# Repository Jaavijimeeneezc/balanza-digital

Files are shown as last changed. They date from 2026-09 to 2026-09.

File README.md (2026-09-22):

# Balanza digital

Lectura automática de básculas analógicas mediante visión por computador. Una
placa ESP32-CAM apunta al display de la báscula y transmite la imagen; el
reconocimiento del peso se hace en el servidor.

## Arquitectura

La placa no calcula el peso. Solo aporta imagen:

1. Se conecta al WiFi y al broker MQTT.
2. Se anuncia en `bascula/{id}/estado` con un mensaje retenido. Ese anuncio
   es todo el descubrimiento: el backend la da de alta sin configurar
   ninguna IP a mano.
3. Sirve video en el puerto 81 y captura puntual en el 80.
4. Escucha órdenes en `bascula/{id}/comando`.

El OCR vive en el backend, que tiene CPU de sobra y se puede afinar sin
reflashear las placas desplegadas.

## Contenido

- `firmware/balanzaDigital_esp32cam/` — firmware principal (MQTT, cámara,
  servidor HTTP).
- `firmware/bascula/` — versión anterior, más simple, que subía las capturas
  por FTP.
- `modelos_3d/` — soporte imprimible en 3D: base, brazo, pie y tapa (STL).

## Dependencias

ArduinoJson, PubSubClient, esp32-camera.

## Configuración

Copia `secrets.h.ejemplo` a `secrets.h` y rellena los valores. `secrets.h`
está en `.gitignore` y no se publica.

## Licencia

MIT. Ver `LICENSE`.

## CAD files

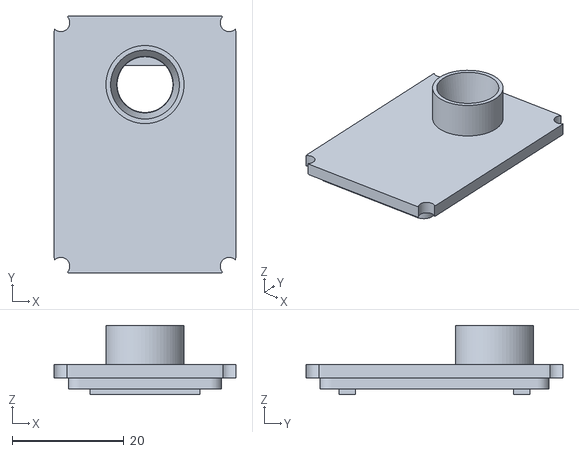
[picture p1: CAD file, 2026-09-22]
modelos_3d/tapa.stl
32.6 x 46.1 x 12.4

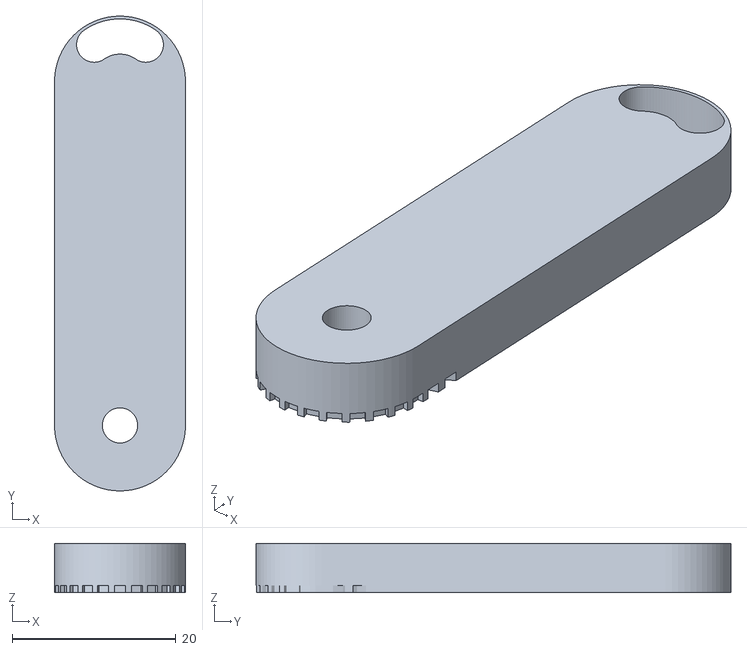
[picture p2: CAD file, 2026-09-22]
modelos_3d/brazo.stl
16.0 x 58.0 x 6.00

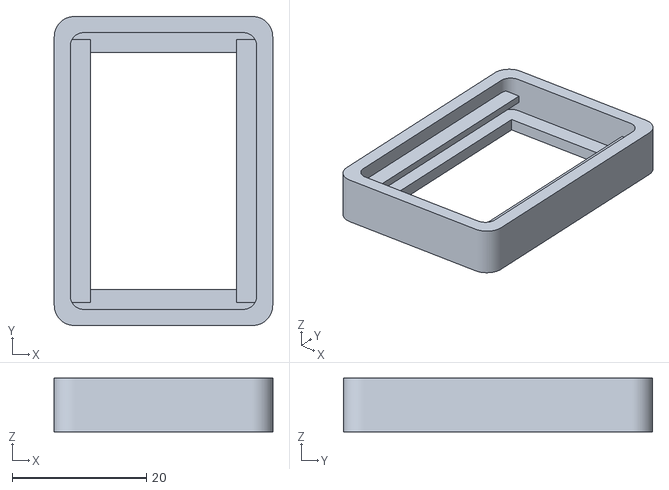
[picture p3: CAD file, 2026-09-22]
modelos_3d/prueba.stl
32.6 x 46.1 x 8.00

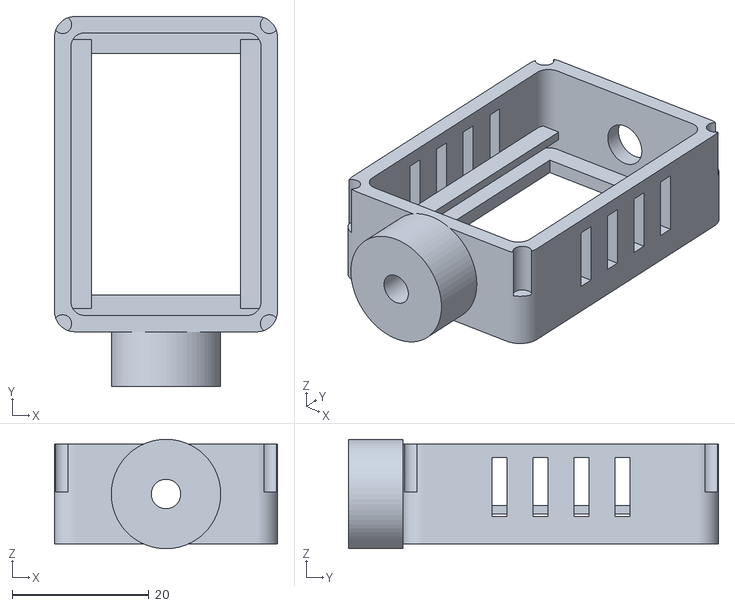
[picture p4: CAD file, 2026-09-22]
modelos_3d/base.stl
32.6 x 54.1 x 16.0

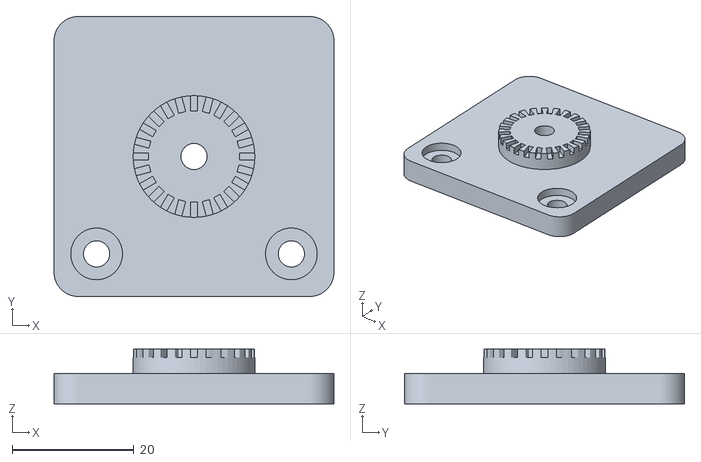
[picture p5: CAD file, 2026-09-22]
modelos_3d/pie.stl
46.0 x 46.0 x 9.00

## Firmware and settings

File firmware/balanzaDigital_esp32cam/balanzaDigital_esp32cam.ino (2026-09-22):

/**
 * balanzaDigital — firmware ESP32-CAM
 *
 * Lo que hace la placa:
 *   1. Se conecta al WiFi y al broker MQTT del servidor.
 *   2. Se anuncia en `bascula/{id}/estado` como mensaje RETENIDO. Ese
 *      anuncio es todo el "descubrimiento": el backend lo lee y la báscula
 *      aparece en la web sin que nadie configure una IP a mano.
 *   3. Sirve el vídeo en :81/stream y el disparo en :80/capture.
 *   4. Escucha órdenes en `bascula/{id}/comando`.
 *
 * El peso NO se calcula aquí: la placa solo da imagen. El OCR lo hace el
 * backend, que tiene CPU de sobra y se puede afinar sin reflashear 20 placas.
 */
#include <Arduino.h>
#include <ArduinoJson.h>
#include <PubSubClient.h>
#include <WiFi.h>
#include <esp_camera.h>

#include "pines_camara.h"
#include "secrets.h"
#include "servidor_web.h"

#define VERSION_FW "1.0.0"

static WiFiClient clienteWifi;
static PubSubClient mqtt(clienteWifi);

static char topicEstado[96];
static char topicDisponibilidad[96];
static char topicComando[96];

static unsigned long ultimoAnuncio = 0;
static const unsigned long INTERVALO_ANUNCIO_MS = 60000;

// ── Cámara ──────────────────────────────────────────────────────────────

static bool iniciarCamara() {
  camera_config_t config = {};
  config.ledc_channel = LEDC_CHANNEL_0;
  config.ledc_timer = LEDC_TIMER_0;
  config.pin_d0 = Y2_GPIO_NUM;
  config.pin_d1 = Y3_GPIO_NUM;
  config.pin_d2 = Y4_GPIO_NUM;
  config.pin_d3 = Y5_GPIO_NUM;
  config.pin_d4 = Y6_GPIO_NUM;
  config.pin_d5 = Y7_GPIO_NUM;
  config.pin_d6 = Y8_GPIO_NUM;
  config.pin_d7 = Y9_GPIO_NUM;
  config.pin_xclk = XCLK_GPIO_NUM;
  config.pin_pclk = PCLK_GPIO_NUM;
  config.pin_vsync = VSYNC_GPIO_NUM;
  config.pin_href = HREF_GPIO_NUM;
  config.pin_sccb_sda = SIOD_GPIO_NUM;
  config.pin_sccb_scl = SIOC_GPIO_NUM;
  config.pin_pwdn = PWDN_GPIO_NUM;
  config.pin_reset = RESET_GPIO_NUM;
  config.xclk_freq_hz = 20000000;
  config.pixel_format = PIXFORMAT_JPEG;

  if (psramFound()) {
    // SVGA (800x600) es el punto dulce: los dígitos del display salen con
    // píxeles de sobra para el OCR y el JPEG sigue cabiendo en RAM.
    config.frame_size = FRAMESIZE_SVGA;
    config.jpeg_quality = 10;  // 10-12 en esta escala; más bajo = mejor calidad
    config.fb_count = 2;
    config.grab_mode = CAMERA_GRAB_LATEST;
    config.fb_location = CAMERA_FB_IN_PSRAM;
  } else {
    // Sin PSRAM no da para más. Si acabas aquí, revisa que la placa la lleve:
    // leer un display a VGA con calidad 12 es jugársela.
    log_w("Sin PSRAM: se baja a VGA");
    config.frame_size = FRAMESIZE_VGA;
    config.jpeg_quality = 12;
    config.fb_count = 1;
    config.fb_location = CAMERA_FB_IN_DRAM;
  }

  esp_err_t err = esp_camera_init(&config);
  if (err != ESP_OK) {
    log_e("esp_camera_init falló: 0x%x", err);
    return false;
  }

  sensor_t *s = esp_camera_sensor_get();
  if (s) {
    // Un display retroiluminado engaña al automático: la cámara expone para
    // el fondo oscuro de la nave y el display sale quemado y blanco. Bajar
    // la exposición y el brillo es lo que hace legibles los dígitos.
    s->set_brightness(s, -1);
    s->set_contrast(s, 2);
    s->set_saturation(s, -2);
    s->set_gainceiling(s, GAINCEILING_2X);
    s->set_ae_level(s, -1);
    s->set_whitebal(s, 1);
    s->set_awb_gain(s, 1);
    // Sin corrección de lente los bordes se curvan y el ROI deja de cuadrar.
    s->set_lenc(s, 1);
  }

  return true;
}

/** Pulso corto de flash. Nunca fijo: recalienta y deslumbra el display. */
static void destelloFlash(uint16_t ms) {
  digitalWrite(FLASH_GPIO_NUM, HIGH);
  delay(ms);
  digitalWrite(FLASH_GPIO_NUM, LOW);
}

// ── WiFi ────────────────────────────────────────────────────────────────

static void conectarWifi() {
  WiFi.mode(WIFI_STA);
  // El ahorro de energía del WiFi mete latencias de cientos de ms en el
  // stream. En una instalación fija con alimentación no compensa.
  WiFi.setSleep(false);
  WiFi.setHostname(BASCULA_ID);
  WiFi.begin(WIFI_SSID, WIFI_PASSWORD);

  Serial.printf("Conectando a %s", WIFI_SSID);
  uint8_t intentos = 0;
  while (WiFi.status() != WL_CONNECTED && intentos < 60) {
    delay(500);
    Serial.print('.');
    intentos++;
  }

  if (WiFi.status() != WL_CONNECTED) {
    Serial.println("\nSin WiFi. Reiniciando.");
    ESP.restart();
  }

  Serial.printf("\nWiFi OK · IP %s · RSSI %d dBm\n", WiFi.localIP().toString().c_str(),
                WiFi.RSSI());
}

// ── MQTT ────────────────────────────────────────────────────────────────

/** Anuncio retenido. Es lo que da de alta la báscula en el backend. */
static void publicarEstado() {
  JsonDocument doc;
  doc["id"] = BASCULA_ID;
  doc["nombre"] = BASCULA_NOMBRE;
  doc["ip"] = WiFi.localIP().toString();
  doc["puerto"] = 80;
  doc["puertoStream"] = 81;
  doc["rssi"] = WiFi.RSSI();
  doc["fw"] = VERSION_FW;
  doc["modelo"] = "esp32cam-ai-thinker";

  sensor_t *s = esp_camera_sensor_get();
  doc["resolucion"] = s ? s->status.framesize : -1;
  doc["frames"] = fotogramasServidos();
  doc["uptime"] = millis() / 1000;

  char payload[320];
  size_t n = serializeJson(doc, payload, sizeof(payload));

  mqtt.publish(topicEstado, (const uint8_t *)payload, n, true);
  ultimoAnuncio = millis();
}

static void alRecibirComando(char *topic, byte *payload, unsigned int longitud) {
  JsonDocument doc;
  if (deserializeJson(doc, payload, longitud)) {
    Serial.println("Comando ilegible");
    return;
  }

  const char *accion = doc["accion"] | "";
  Serial.printf("Comando recibido: %s\n", accion);

  if (!strcmp(accion, "reiniciar")) {
    mqtt.publish(topicDisponibilidad, "offline", true);
    delay(200);
    ESP.restart();

  } else if (!strcmp(accion, "flash")) {
    destelloFlash(doc["ms"] | 150);

  } else if (!strcmp(accion, "resolucion")) {
    sensor_t *s = esp_camera_sensor_get();
    if (s) {
      s->set_framesize(s, (framesize_t)(doc["valor"] | FRAMESIZE_SVGA));
      // El sensor tarda un par de fotogramas en estabilizarse tras el cambio.
      delay(300);
      publicarEstado();
    }

  } else if (!strcmp(accion, "estado")) {
    publicarEstado();
  }
}

static void conectarMqtt() {
  while (!mqtt.connected()) {
    Serial.print("Conectando a MQTT... ");

    // El LWT es lo que hace que la web marque la báscula en rojo cuando se
    // va la corriente: el broker publica "offline" por nosotros.
    bool ok = mqtt.connect(BASCULA_ID, MQTT_USER, MQTT_PASSWORD, topicDisponibilidad, 1, true,
                           "offline");

    if (ok) {
      Serial.println("OK");
      mqtt.publish(topicDisponibilidad, "online", true);
      mqtt.subscribe(topicComando, 1);
      publicarEstado();
    } else {
      Serial.printf("falló (rc=%d), reintento en 5 s\n", mqtt.state());
      delay(5000);
    }
  }
}

// ── Arranque ────────────────────────────────────────────────────────────

void setup() {
  Serial.begin(115200);
  Serial.setDebugOutput(false);
  Serial.printf("\n\nbalanzaDigital · %s · fw %s\n", BASCULA_ID, VERSION_FW);

  pinMode(FLASH_GPIO_NUM, OUTPUT);
  digitalWrite(FLASH_GPIO_NUM, LOW);

  snprintf(topicEstado, sizeof(topicEstado), "%s/%s/estado", MQTT_TOPIC_PREFIX, BASCULA_ID);
  snprintf(topicDisponibilidad, sizeof(topicDisponibilidad), "%s/%s/disponibilidad",
           MQTT_TOPIC_PREFIX, BASCULA_ID);
  snprintf(topicComando, sizeof(topicComando), "%s/%s/comando", MQTT_TOPIC_PREFIX, BASCULA_ID);

  if (!iniciarCamara()) {
    Serial.println("Cámara KO. Reiniciando en 5 s.");
    delay(5000);
    ESP.restart();
  }

  conectarWifi();

  if (iniciarServidorWeb() != ESP_OK) {
    Serial.println("Servidor HTTP KO. Reiniciando en 5 s.");
    delay(5000);
    ESP.restart();
  }

  mqtt.setServer(MQTT_HOST, MQTT_PORT);
  mqtt.setCallback(alRecibirComando);
  mqtt.setBufferSize(512);
  mqtt.setKeepAlive(30);
  conectarMqtt();

  Serial.printf("Listo. Stream en http://%s:81/stream\n", WiFi.localIP().toString().c_str());
  destelloFlash(80);  // Señal visual de que arrancó bien.
}

void loop() {
  if (WiFi.status() != WL_CONNECTED) {
    Serial.println("WiFi caído. Reiniciando.");
    ESP.restart();
  }

  if (!mqtt.connected()) conectarMqtt();
  mqtt.loop();

  // Reanuncio periódico: si el broker pierde los retenidos o el backend se
  // reinstala desde cero, la báscula vuelve a aparecer sin tocar nada.
  if (millis() - ultimoAnuncio > INTERVALO_ANUNCIO_MS) publicarEstado();

  delay(10);
}

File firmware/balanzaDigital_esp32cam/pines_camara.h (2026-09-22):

#pragma once

// Pinout de la ESP32-CAM de AI-Thinker (la de la foto: módulo con ranura
// microSD, conector IPEX para antena externa y flash en GPIO 4).
//
// Si montas otra placa (M5Stack, TTGO, XIAO ESP32S3 Sense...) hay que
// cambiar este bloque entero: los pines no son compatibles entre sí.

#define PWDN_GPIO_NUM   32
#define RESET_GPIO_NUM  -1
#define XCLK_GPIO_NUM    0
#define SIOD_GPIO_NUM   26
#define SIOC_GPIO_NUM   27

#define Y9_GPIO_NUM     35
#define Y8_GPIO_NUM     34
#define Y7_GPIO_NUM     39
#define Y6_GPIO_NUM     36
#define Y5_GPIO_NUM     21
#define Y4_GPIO_NUM     19
#define Y3_GPIO_NUM     18
#define Y2_GPIO_NUM      5

#define VSYNC_GPIO_NUM  25
#define HREF_GPIO_NUM   23
#define PCLK_GPIO_NUM   22

// LED blanco de alta potencia. Ojo: calienta y deslumbra el display si lo
// dejas fijo; úsalo solo en pulsos cortos durante la captura.
#define FLASH_GPIO_NUM   4

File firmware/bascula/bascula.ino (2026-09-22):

#include <WiFi.h>
#include <WiFiClient.h>
#include "esp_camera.h"

// ================= DATOS A RELLENAR =================
const char* ssid = "";         // <-- TU WIFI
const char* password = "";    // <-- TU CLAVE

// IP de tu PC (Donde corre el Python)
const char* ftp_server = ""; // <-- ¡REVISA TU IP CON ipconfig!
const char* ftp_user = "";
const char* ftp_pass = "";
const int ftp_port = 21;
// ====================================================

// Configuración de pines para AI Thinker ESP32-CAM
#define PWDN_GPIO_NUM     32
#define RESET_GPIO_NUM    -1
#define XCLK_GPIO_NUM     0
#define SIOD_GPIO_NUM     26
#define SIOC_GPIO_NUM     27
#define Y9_GPIO_NUM       35
#define Y8_GPIO_NUM       34
#define Y7_GPIO_NUM       39
#define Y6_GPIO_NUM       36
#define Y5_GPIO_NUM       21
#define Y4_GPIO_NUM       19
#define Y3_GPIO_NUM       18
#define Y2_GPIO_NUM       5
#define VSYNC_GPIO_NUM    25
#define HREF_GPIO_NUM     23
#define PCLK_GPIO_NUM     22

WiFiClient client; // Cliente para comandos (Puerto 21)

// Declaramos la función antes para evitar errores
String leerRespuesta();

void setup() {
  Serial.begin(115200);
  
  // Configuración de la cámara
  camera_config_t config;
  config.ledc_channel = LEDC_CHANNEL_0;
  config.ledc_timer = LEDC_TIMER_0;
  config.pin_d0 = Y2_GPIO_NUM;
  config.pin_d1 = Y3_GPIO_NUM;
  config.pin_d2 = Y4_GPIO_NUM;
  config.pin_d3 = Y5_GPIO_NUM;
  config.pin_d4 = Y6_GPIO_NUM;
  config.pin_d5 = Y7_GPIO_NUM;
  config.pin_d6 = Y8_GPIO_NUM;
  config.pin_d7 = Y9_GPIO_NUM;
  config.pin_xclk = XCLK_GPIO_NUM;
  config.pin_pclk = PCLK_GPIO_NUM;
  config.pin_vsync = VSYNC_GPIO_NUM;
  config.pin_href = HREF_GPIO_NUM;
  config.pin_sscb_sda = SIOD_GPIO_NUM;
  config.pin_sscb_scl = SIOC_GPIO_NUM;
  config.pin_pwdn = PWDN_GPIO_NUM;
  config.pin_reset = RESET_GPIO_NUM;
  config.xclk_freq_hz = 20000000;
  config.pixel_format = PIXFORMAT_JPEG;
  
  if(psramFound()){
    config.frame_size = FRAMESIZE_VGA; // Calidad media (640x480)
    config.jpeg_quality = 10;
    config.fb_count = 2;
  } else {
    config.frame_size = FRAMESIZE_SVGA;
    config.jpeg_quality = 12;
    config.fb_count = 1;
  }

  // Iniciar cámara
  if (esp_camera_init(&config) != ESP_OK) {
    Serial.println("Error al iniciar la cámara");
    return;
  }

  // Conectar a WiFi
  WiFi.begin(ssid, password);
  Serial.print("Conectando a WiFi");
  while (WiFi.status() != WL_CONNECTED) {
    delay(500);
    Serial.print(".");
  }
  Serial.println("");
  Serial.println("WiFi Conectado!");
}

void loop() {
  // 1. Tomar Foto
  Serial.println("---------------------------");
  Serial.println("Tomando foto...");
  camera_fb_t * fb = esp_camera_fb_get();
  if (!fb) {
    Serial.println("Fallo al capturar imagen");
    delay(5000);
    return;
  }

  // 2. Conectar al Servidor (Canal de Control)
  if (client.connect(ftp_server, ftp_port)) {
    Serial.println("Conectado al servidor FTP!");
    leerRespuesta(); // Saludo del servidor

    // Login
    client.println("USER " + String(ftp_user));
    leerRespuesta();
    client.println("PASS " + String(ftp_pass));
    leerRespuesta();

    // 3. ACTIVAR MODO PASIVO
    client.println("PASV");
    String respuesta = leerRespuesta(); 
    
    // Buscar paréntesis y calcular puerto
    int inicio = respuesta.indexOf('(');
    int fin = respuesta.indexOf(')');
    
    if (inicio != -1 && fin != -1) {
      String datos = respuesta.substring(inicio + 1, fin);
      
      int coma5 = datos.lastIndexOf(',');
      int p2 = datos.substring(coma5 + 1).toInt(); 
      
      String resto = datos.substring(0, coma5);
      int coma4 = resto.lastIndexOf(',');
      int p1 = resto.substring(coma4 + 1).toInt(); 
      
      // Fórmula FTP: (p1 * 256) + p2
      int puertoDatos = (p1 * 256) + p2;
      Serial.print("Puerto de datos calculado: ");
      Serial.println(puertoDatos);

      // 4. Conectar al Canal de Datos
      WiFiClient dataClient;
      if (dataClient.connect(ftp_server, puertoDatos)) {
        Serial.println("Canal de datos abierto CORRECTAMENTE!");
        
        // Avisar subida
        String nombreArchivo = "foto_" + String(millis()) + ".jpg";
        client.println("STOR " + nombreArchivo);
        leerRespuesta();

        // 5. ENVIAR LA FOTO
        size_t totalBytes = fb->len;
        size_t sentBytes = 0;
        const size_t chunkSize = 1024;
        uint8_t *buffer = fb->buf;

        while (sentBytes < totalBytes) {
            size_t bytesToRead = totalBytes - sentBytes;
            if (bytesToRead > chunkSize) bytesToRead = chunkSize;
            dataClient.write(buffer + sentBytes, bytesToRead);
            sentBytes += bytesToRead;
        }
        
        dataClient.stop(); // Cerrar canal de datos
        Serial.println("Foto subida: " + nombreArchivo);
        
        leerRespuesta(); // Respuesta final
      } else {
        Serial.println("Error: No se pudo conectar al puerto de datos (Firewall?)");
      }
    } else {
      Serial.println("Error: El servidor no respondió bien al comando PASV");
    }
    
    client.println("QUIT");
    client.stop();
    Serial.println("Desconectado.");
  } else {
    Serial.println("Error al conectar con el servidor FTP (Revisa IP).");
  }

  esp_camera_fb_return(fb); // Liberar memoria
  
  // Esperar 10 segundos antes de la siguiente foto
  delay(10000); 
}

// Función auxiliar para leer respuesta del servidor
String leerRespuesta() {
  String resp = "";
  unsigned long tiempo = millis();
  while (client.connected() && !client.available() && millis() - tiempo < 5000) {
    delay(1); 
  }
  while (client.available()) {
    char c = client.read();
    resp += c;
  }
  // Descomenta si quieres ver todo el chat en el monitor
  // Serial.print("S: "); Serial.println(resp); 
  return resp;
}
